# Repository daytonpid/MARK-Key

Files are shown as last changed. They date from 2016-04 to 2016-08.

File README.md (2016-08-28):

# MARK-Key
A authentication key for MARK ( Mutual Authentication to Resist Keylogging )

## White Paper: http://dx.doi.org/10.1145/2663348

## Implementation: https://www1.cs.fau.de/filepool/projects/mark/index.html

## Purpose: To provide users of the MARK implementation with openly available board design files for the authentication key.

### TODO:

- [x] Update the outdated implementation for use with the latest Linux Kernel

- [ ] Provide Documentation

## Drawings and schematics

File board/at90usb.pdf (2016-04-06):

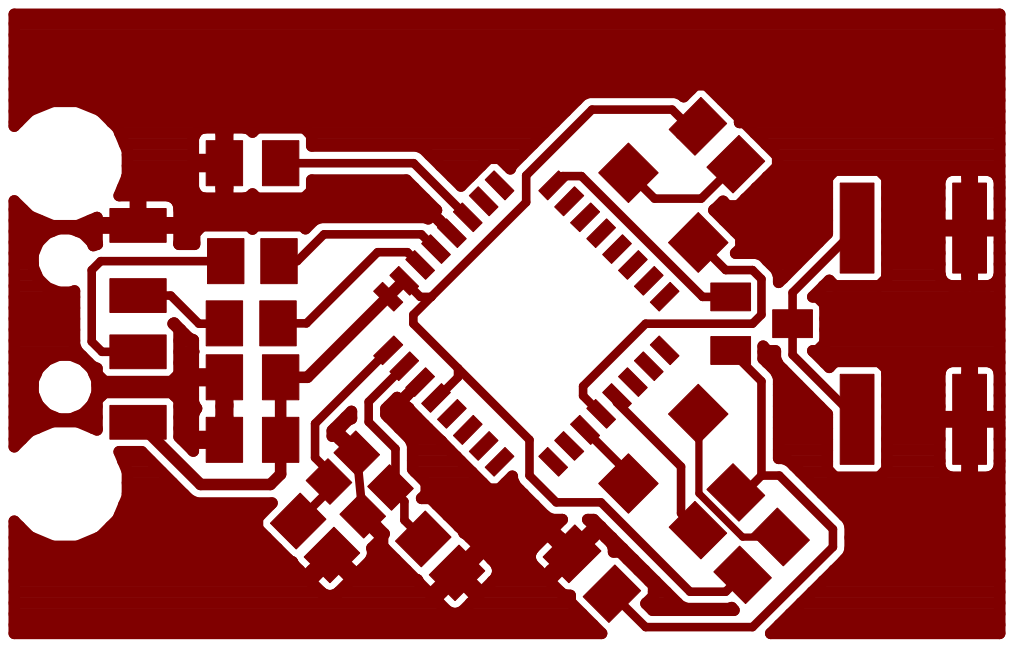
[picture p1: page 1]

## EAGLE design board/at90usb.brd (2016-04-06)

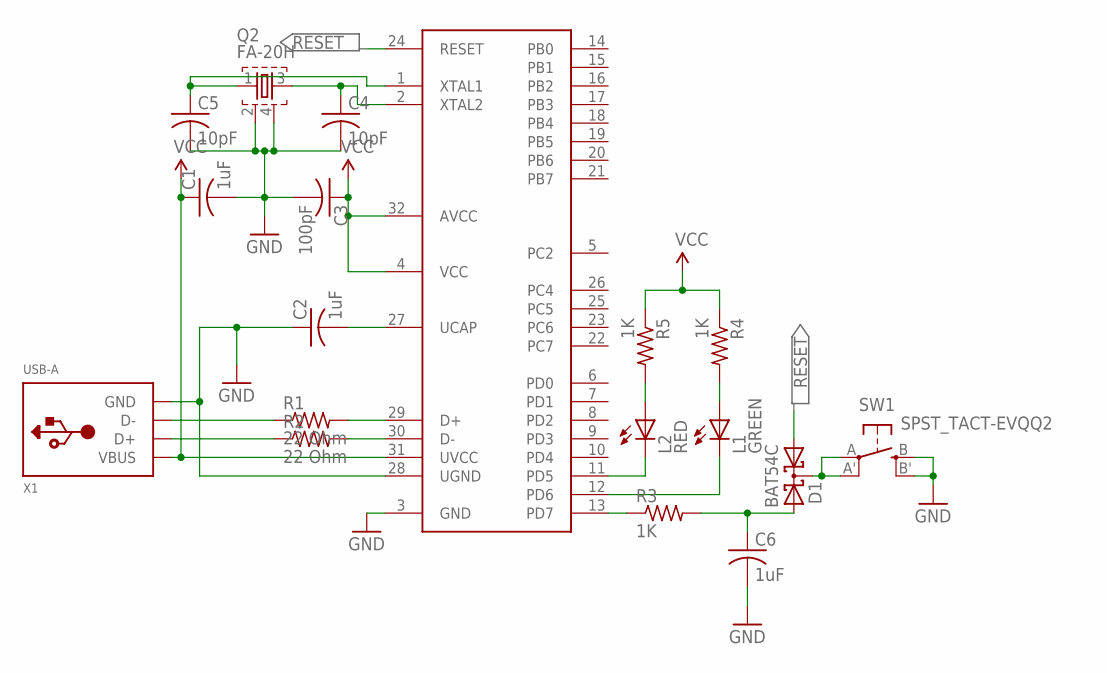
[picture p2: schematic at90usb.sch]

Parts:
C1, C2, C6: 1uF; C0805K; MPN 06033D105MAT2A
C3: 100pF; C0805K; MPN 0603YC104K4Z2A
C4, C5: 10pF; C0805
D1: BAT54C; SOT23
L1: GREEN; CHIPLED_1206
L2: RED; CHIPLED_1206
Q2: FA-20H
R1, R2: 22 Ohm; M0805
R3, R4, R5: 1K; M0805
SW1: SPST_TACT-EVQQ2; EVQ-Q2
U1: AT90USB162; VQFP32
X1: USB-A; MOLEX_480371000

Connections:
GND: C1.2, C2.1, C3.2, C4.2, C5.2, C6.2, Q2.2, Q2.4, SW1.B (S), SW1.B' (S1), U1.3 (GND), U1.28 (UGND), X1.4 (GND)
unnamed: R1.2, U1.29 (D+)
unnamed: R2.2, U1.30 (D-)
unnamed: R1.1, X1.2 (D-)
unnamed: R2.1, X1.3 (D+)
unnamed: D1.3 (CC), SW1.A, SW1.A' (P1)
unnamed: C5.1, Q2.1, U1.1 (XTAL1)
unnamed: C2.2, U1.27 (UCAP)
unnamed: C4.1, Q2.3, U1.2 (XTAL2)
unnamed: C6.1, D1.2 (A2), R3.2
unnamed: R3.1, U1.13 (PD7)
unnamed: L1.C, U1.12 (PD6)
unnamed: L1.A, R4.2
unnamed: L2.C, U1.11 (PD5)
unnamed: L2.A, R5.2
RESET: D1.1 (A1), U1.24 (RESET)
VCC: C1.1, C3.1, R4.1, R5.1, U1.4 (VCC), U1.31 (UVCC), U1.32 (AVCC), X1.1 (VBUS)

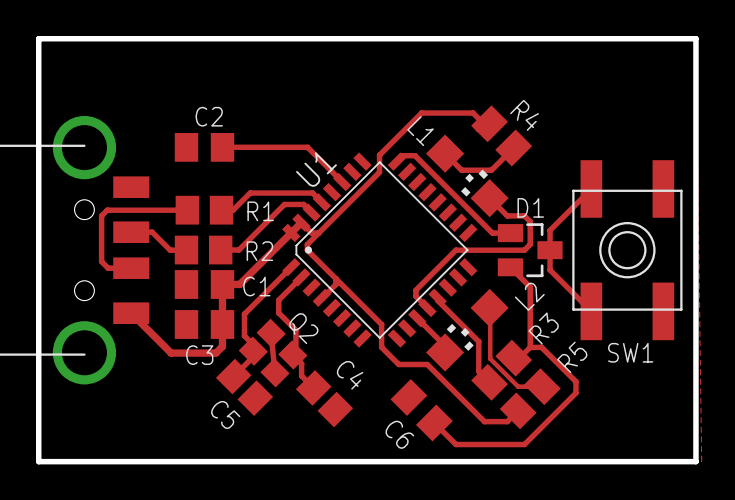
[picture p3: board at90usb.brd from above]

Board: 2 copper layers, 36.5 x 23.5 mm, 18 parts (0 on the bottom side), 17 nets.

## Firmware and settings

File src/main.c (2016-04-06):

/*
 * Serial nonce verification with Teensy USB
 *
 * Copyright (C) 2013 Johannes Goetzfried <johannes@jgoetzfried.de>
 *
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
 * You should have received a copy of the GNU General Public License along with
 * this program; if not, write to the Free Software Foundation, Inc., 59 Temple
 * Place - Suite 330, Boston, MA 02111-1307 USA.
 */

#include <avr/io.h>
#include <avr/pgmspace.h>
#include <avr/eeprom.h>
#include <util/delay.h>
#include <stdint.h>
#include <string.h>
#include "usb_serial.h"

#define NONCESIZE 64

#define LED_CONFIG	(DDRD |= (1<<6))
#define LED_ON		(PORTD &= ~(1<<6))
#define LED_OFF		(PORTD |= (1<<6))
#define CPU_PRESCALE(n) (CLKPR = 0x80, CLKPR = (n))

#define BLINK(delay)      \
	LED_ON;           \
	_delay_ms(delay); \
	LED_OFF;          \
	_delay_ms(delay); \
	LED_ON;           \
	_delay_ms(delay); \
	LED_OFF;          \
	_delay_ms(delay); \
	LED_ON;           \
	_delay_ms(delay); \
	LED_OFF;

static uint8_t g_ee_nonce[NONCESIZE] EEMEM = {
	'4', '2', '4', '2', '4', '2', '4', '2',
	'4', '2', '4', '2', '4', '2', '4', '2',
	'4', '2', '4', '2', '4', '2', '4', '2',
	'4', '2', '4', '2', '4', '2', '4', '2',
	'4', '2', '4', '2', '4', '2', '4', '2',
	'4', '2', '4', '2', '4', '2', '4', '2',
	'4', '2', '4', '2', '4', '2', '4', '2',
	'4', '2', '4', '2', '4', '2', '4', '2' };


static void send_str(const char *s);
static uint8_t recv_str(char *buf, uint8_t size);
static void do_command(char *buf, uint8_t n);

static uint8_t g_nonce[NONCESIZE];
static uint8_t g_verifycnt = 0;
static uint8_t g_verified = 0;

int main(void)
{
	char buf[128];
	uint8_t n;

	CPU_PRESCALE(0);

	usb_init();
	while (!usb_configured()) /* wait */ ;

	/* led blink; waiting time is mandatory */
	LED_CONFIG;
	BLINK(200);

	// read nonce from eeprom
	eeprom_read_block(g_nonce, g_ee_nonce, NONCESIZE);

	// wait for the user to run their terminal emulator program
	// which sets DTR to indicate it is ready to receive.
	while (!(usb_serial_get_control() & USB_SERIAL_DTR)) /* wait */ ;
	usb_serial_flush_input();

	send_str(PSTR("200 Welcome\r\n"));

	while (1) {
		n = recv_str(buf, sizeof(buf));
		if (g_verifycnt < 3)
			do_command(buf, n);
		else
			send_str(PSTR("404 Number of tries exceeded\r\n"));
	}
}


static void send_str(const char *s)
{
	char c;
	while (1) {
		c = pgm_read_byte(s++);
		if (!c) break;
		usb_serial_putchar(c);
	}
}

static uint8_t recv_str(char *buf, uint8_t size)
{
	int16_t r;
	uint8_t count = 0;

	while (count < size) {
		r = usb_serial_getchar();
		if (r != -1) {
			if (r == '\r' || r == '\n') return count;
			if (r >= ' ' && r <= '~') {
				*buf++ = r;
				count++;
			}
		}
	}
	return count;
}

/* command syntax: command<space>operand\n
 * commands:
 *   verify <nonce>
 *   store <nonce>
 * <nonce> is exactly NONCESIZE chars
 */
static void do_command(char *buf, uint8_t n)
{
	if (!strncmp_P(buf, PSTR("verify"), 6) && g_verified == 0) {
		if (!memcmp(buf + 7, g_nonce, NONCESIZE)) {
			g_verified = 1;
			LED_ON;
			send_str(PSTR("201 Verified\r\n"));
		}
		else {
			g_verifycnt++;
			BLINK(100);
			send_str(PSTR("401 Verification failed\r\n"));
		}
	}
	else if (!strncmp_P(buf, PSTR("store"), 5)) {
		if (g_verified == 0) {
			send_str(PSTR("402 Not verified\r\n"));
		}
		else if (n < 6 + NONCESIZE) {
			send_str(PSTR("403 Invalid nonce\r\n"));
		}
		else {
			eeprom_write_block(buf + 6, g_ee_nonce, NONCESIZE);
			send_str(PSTR("202 Nonce written\r\n"));
		}
	}
	else {
		send_str(PSTR("400 Unknown command\r\n"));
	}
}

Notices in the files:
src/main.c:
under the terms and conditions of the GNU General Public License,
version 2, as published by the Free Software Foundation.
